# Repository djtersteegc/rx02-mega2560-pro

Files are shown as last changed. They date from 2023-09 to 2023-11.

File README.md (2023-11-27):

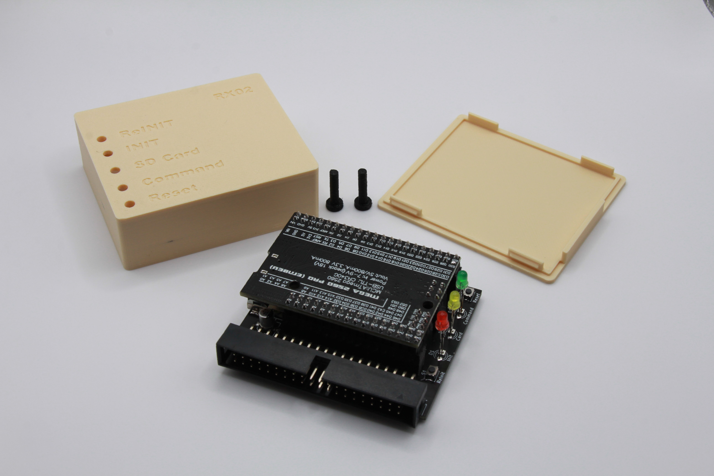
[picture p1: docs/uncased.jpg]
uncased


Mega 2560 Pro Embed version on [AK6DN's DEC RX02 emulator](https://github.com/AK6DN/rx02_emulator) board design and code.  There is a fork of his project at  https://github.com/djtersteegc/rx02_emulator that adds software support for this new board design. This was an exercise in how small I could make it while still using a Mega2560 shield and large'ish 0805 SMD parts for an easy DIY build.  If you are interested in a larger version built on a standard Arduino Mega 2560  with an LCD and buttons so you don't need to pick images via a serial/terminal connection, see my other project at https://github.com/djtersteegc/rx02-emulator-mega-shield.

Here's the two of them side by side on a Heathkit H11 for a size comparison.

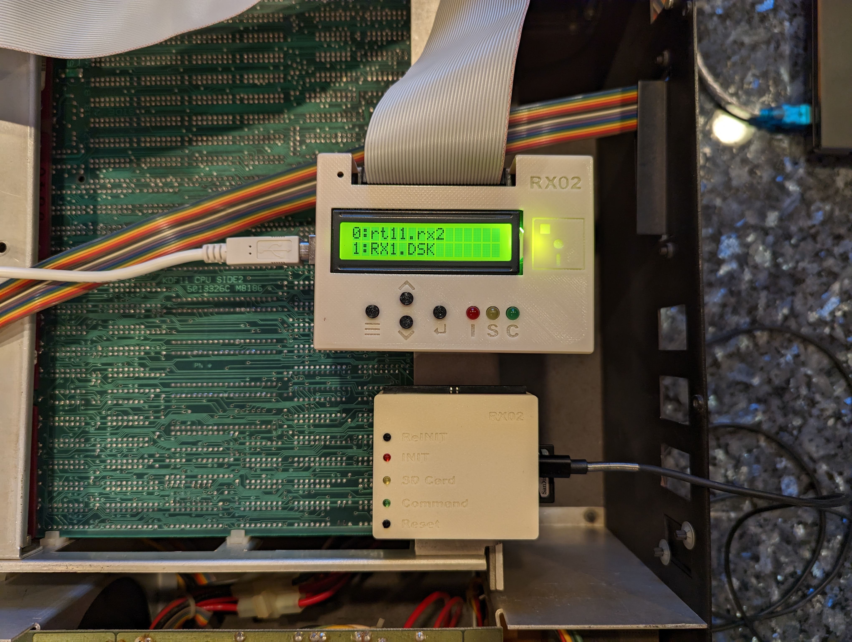
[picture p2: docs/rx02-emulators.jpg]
rx02-emulators


See the VCFed thread at https://forum.vcfed.org/index.php?threads/building-the-worlds-currently-smallest-rx02-emulator.1240496/ for discussion or help with this project

# BOM

There is an interactive BOM at https://djtersteegc.github.io/rx02-mega2560-pro/ibom-v1.2.html  It's for a version 1.2 board which is hasn't been produced yet so ignore R32 and D4 which are for a power indicator LED if you are building a version 1.1 board.

C1 and C2 are bulk storage caps for the 5V rail, any value over 33uF should do.  C7 is a 47uF tantalum to prevent sag on the 3.3V rail when hot swapping the SD card since there is usually quite a bit of in rush current.  You can probably do without, especially if you never intend to hot swap since it's not really supported by the firmware.

The SD card connector is commonly available from several different Chinese suppliers and often called "long body", "non popping", or"push pull".  Here's some links on LCSC.

https://www.lcsc.com/product-detail/SD-Card-Connectors_Hanbo-Electronic-SD-112_C961673.html

https://www.lcsc.com/product-detail/SD-Card-Connectors_XUNPU-SD-102_C266602.html

https://www.lcsc.com/product-detail/SD-Card-Connectors_Megastar-ZX-SD-282-8Y_C7419835.html

It should also cross with a Wurth 693063010911 or AMP GSD090012SEU if you want something domestically.

You can also use BSS138 FET's in place of the 2N7002's.

# Assembly

This time around I used the same resistor references as AK6DN's original version so his resistor stuffing table is the same. Most of the resistor footprints should NOT be populated.

| Signal | Resistor | Value | Resistor | Value |
| --- | --- | --- | --- | --- |
| RX_DMA_MODE_H  | R2 | - | R3 | **390** |
| RX_AC_L | R4 | **120** | R5 | - |
| RX_OUT_L | R6 | - | R7 | - |
| RX_SHIFT_L | R8 | - | R9 | - |
| RX_12BIT_L | R10 | **180** | R23 | **390** |
| RX_DATA_L | R11 | **180** | R12 | **390** |
| RX_DONE_L | R13 | - | R14 | - |
| RX_XFER_RQST_L | R15 | - | R16 | - |
| RX_INIT_L | R17 | - | R18 | **390** |
| RX_ERROR_L | R19 | - | R20 | - |
| RX_RUN_L | R21 | **180** | R22 | **390** |

Assemble the top side first.

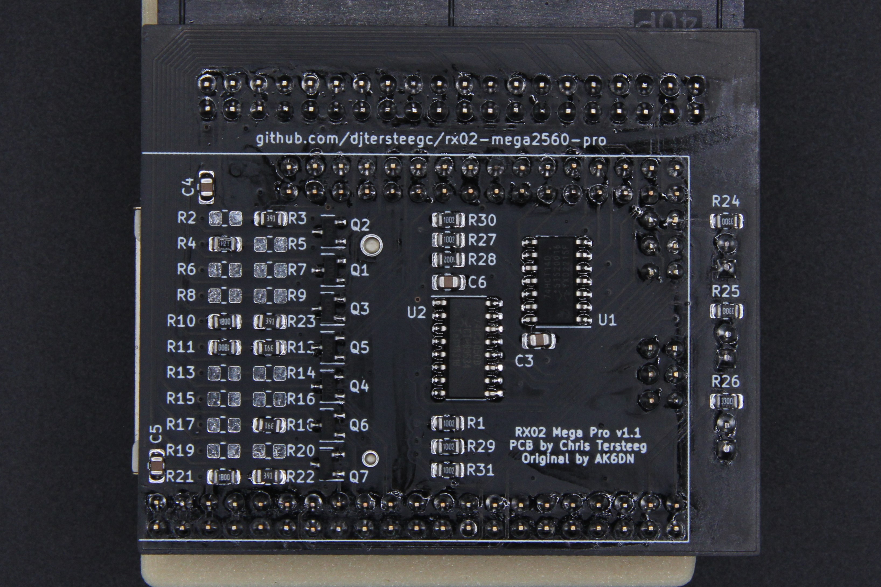
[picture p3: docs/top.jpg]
top


Then flip in over and do the bottom.  Followed by the headers and then the 40 pin connector. For the LED's, I first insert them in the PCB, then the PCB in the case, flip it over and support the case ~1mm off the work surface for the LED's to just poke through the top and get a nice reveal. Solder one leg on the LED's, flip it over to check your spacing again, and then solder the other leg.

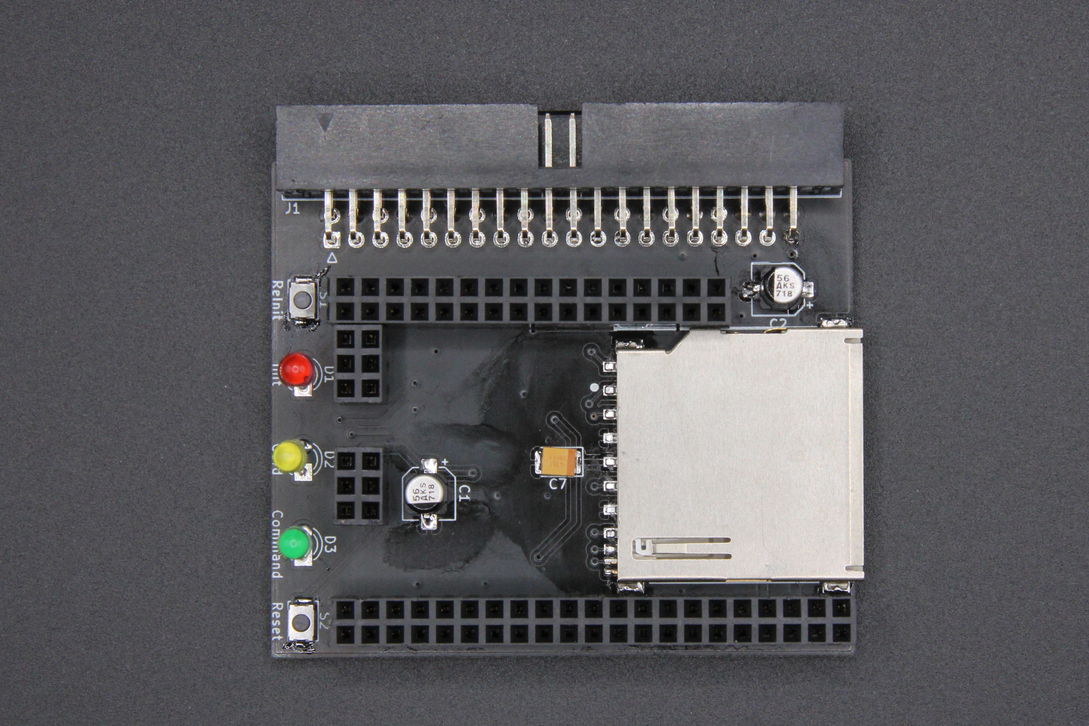
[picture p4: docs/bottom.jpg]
bottom


# Case

Make sure to print two copies of the buttons. Angle the board in connector side first and it should drop in.  It's a snap fit design, so no screws needed to assemble.

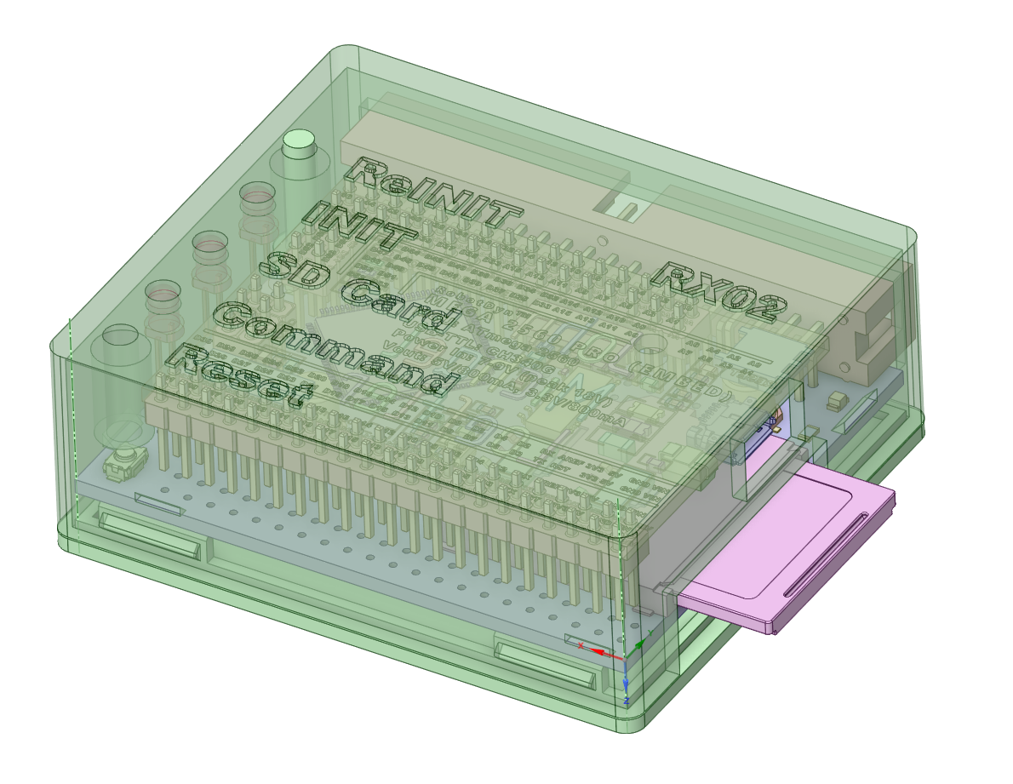
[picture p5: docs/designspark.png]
case


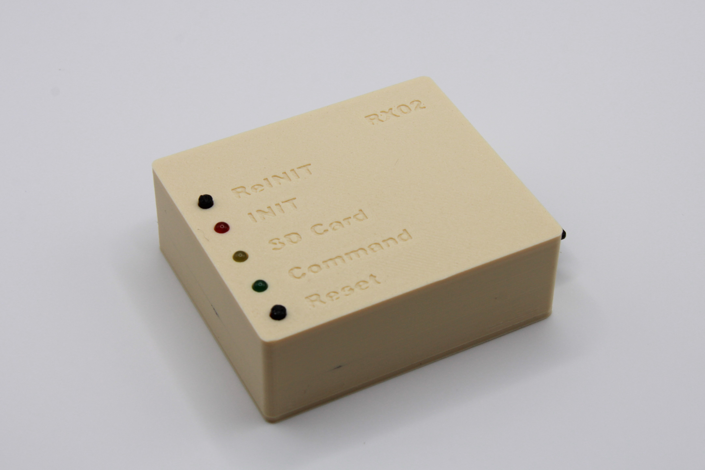
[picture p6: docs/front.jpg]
front


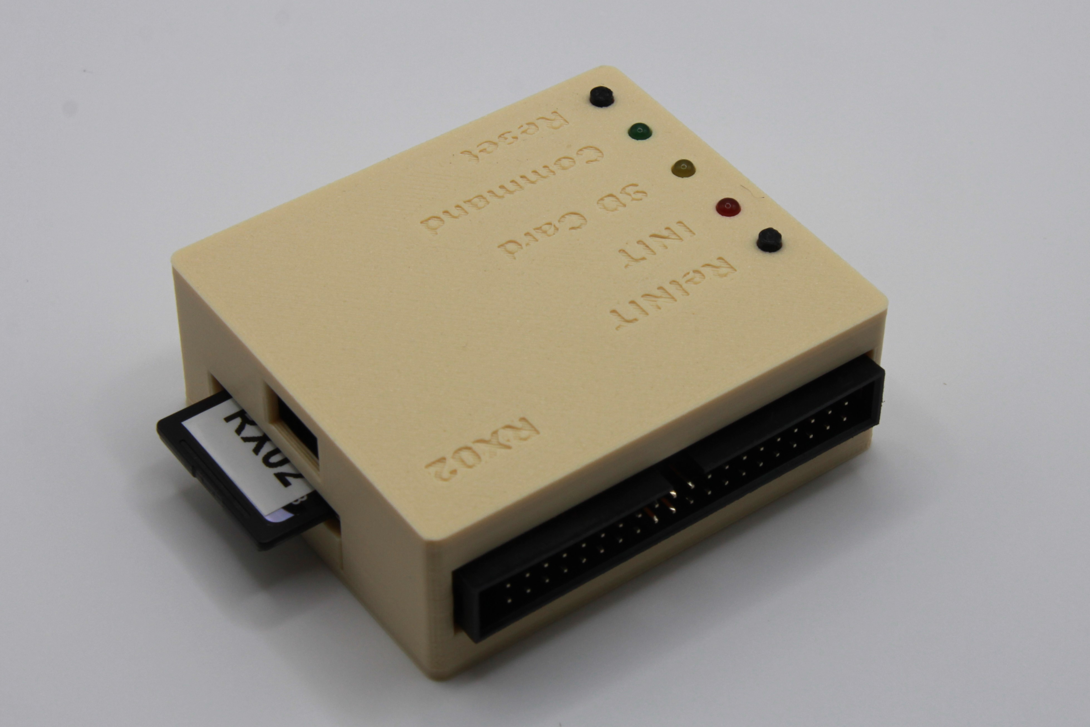
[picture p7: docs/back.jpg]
back


# Flashing and Usage

See instructions at https://github.com/djtersteegc/rx02_emulator

# Getting a Board

If you are in the US, hit me up on the [VCFed thread](https://forum.vcfed.org/index.php?threads/building-the-worlds-currently-smallest-rx02-emulator.1240496/) above and if I still have extras, I can drop one in the mail for a couple of bucks. Otherwise, grab the gerbers and fab your own.

# Hardware Revisions

### Version 1.0

Required bodge wires since I failed to pick interrupt enabled pins on the Mega2560 for the RX_INIT and RX_RUN lines when I reamapped the pins to better fit this layout.

### Versions 1.1 (Current)

Working

### Version 1.2 (Not Produced Yet)

Added a power LED

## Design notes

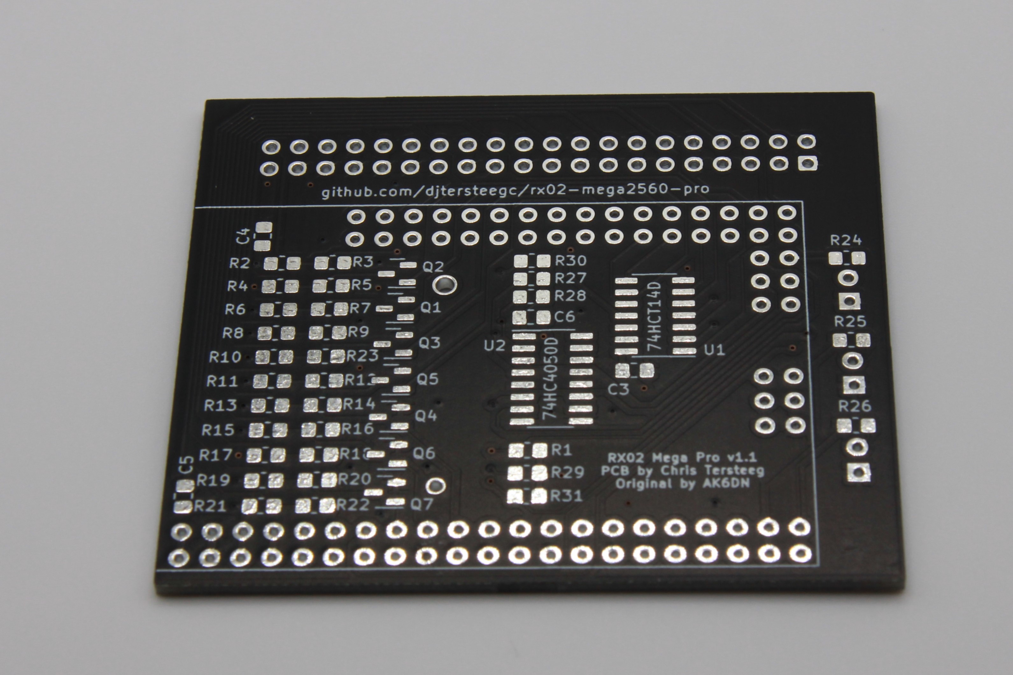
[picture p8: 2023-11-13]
docs/pcb-top.jpg

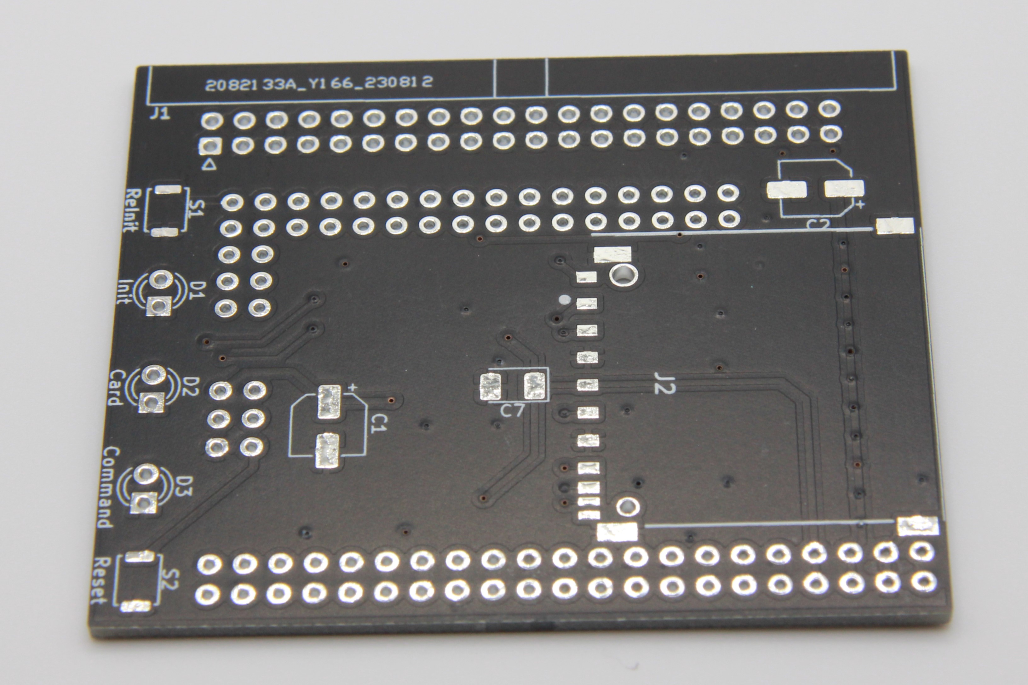
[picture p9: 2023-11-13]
docs/pcb-bottom.jpg

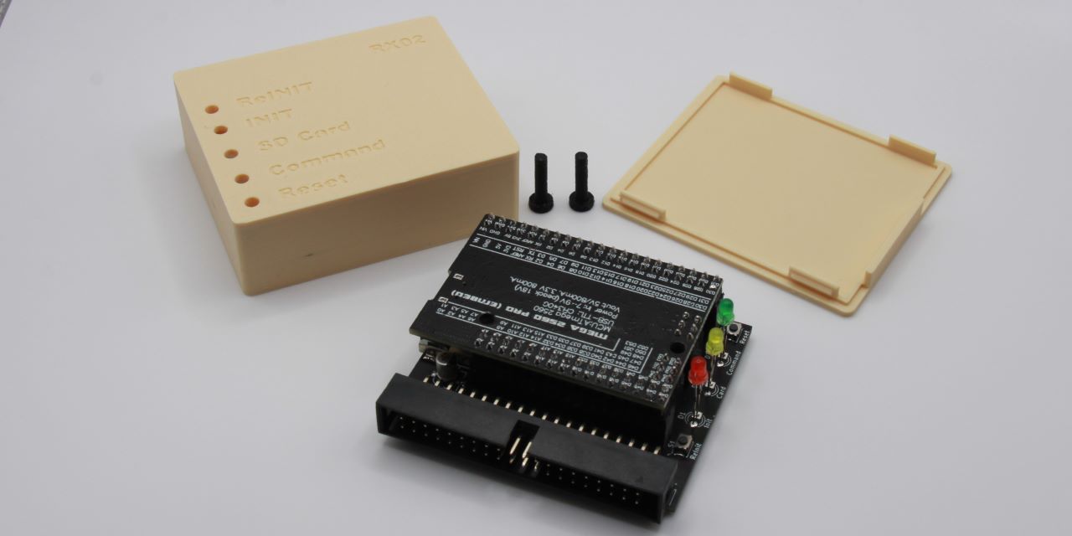
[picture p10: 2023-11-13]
docs/social.jpg

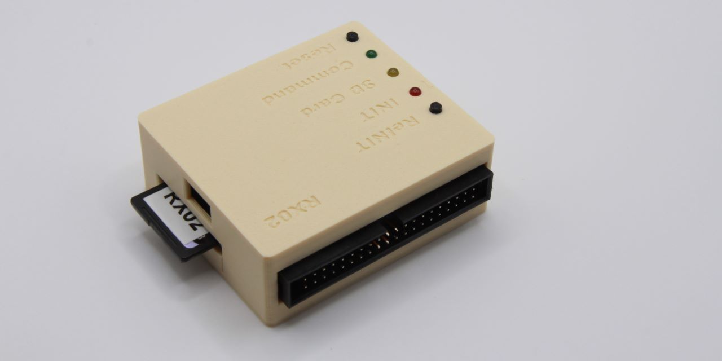
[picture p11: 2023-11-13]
docs/social2.jpg

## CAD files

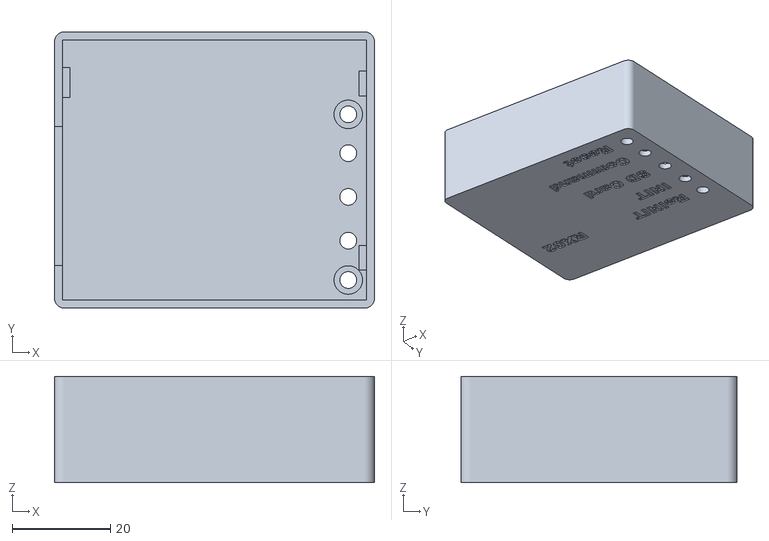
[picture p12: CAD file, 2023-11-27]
case/STL/rx02-mega2560-pro-body.stl
65.0 x 56.1 x 21.6

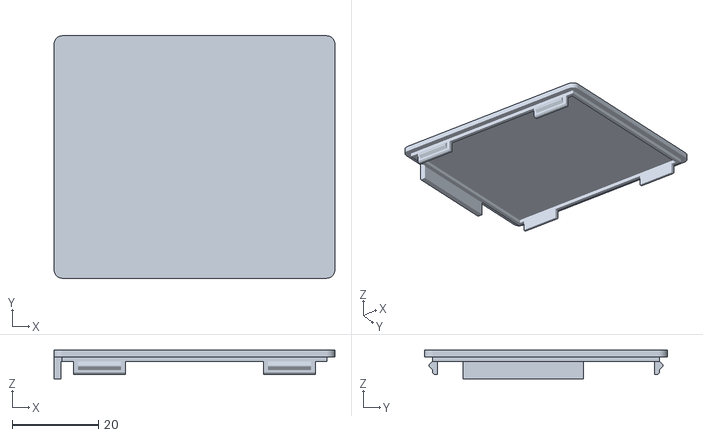
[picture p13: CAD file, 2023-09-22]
case/STL/rx02-mega2560-pro-lid.stl
65.0 x 56.1 x 6.68

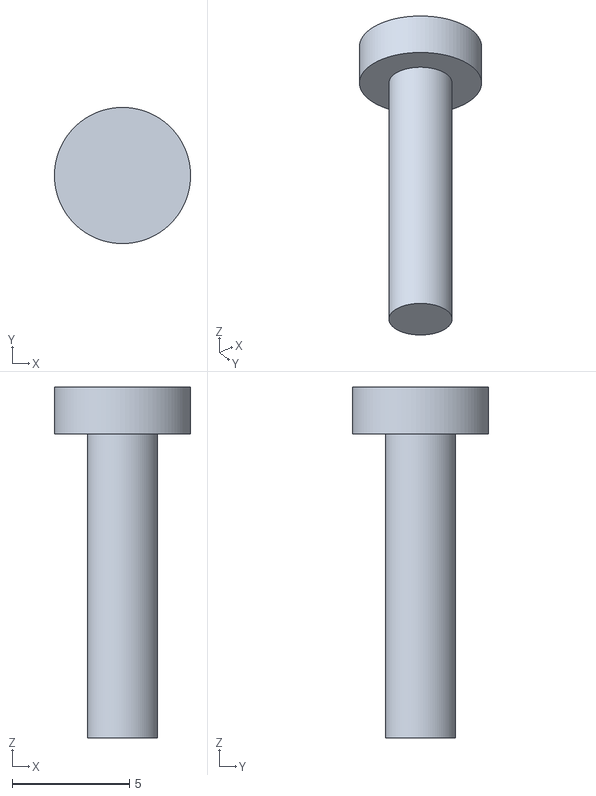
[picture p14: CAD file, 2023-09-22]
case/STL/rx02-mega2560-button.stl
5.80 x 5.80 x 15.0

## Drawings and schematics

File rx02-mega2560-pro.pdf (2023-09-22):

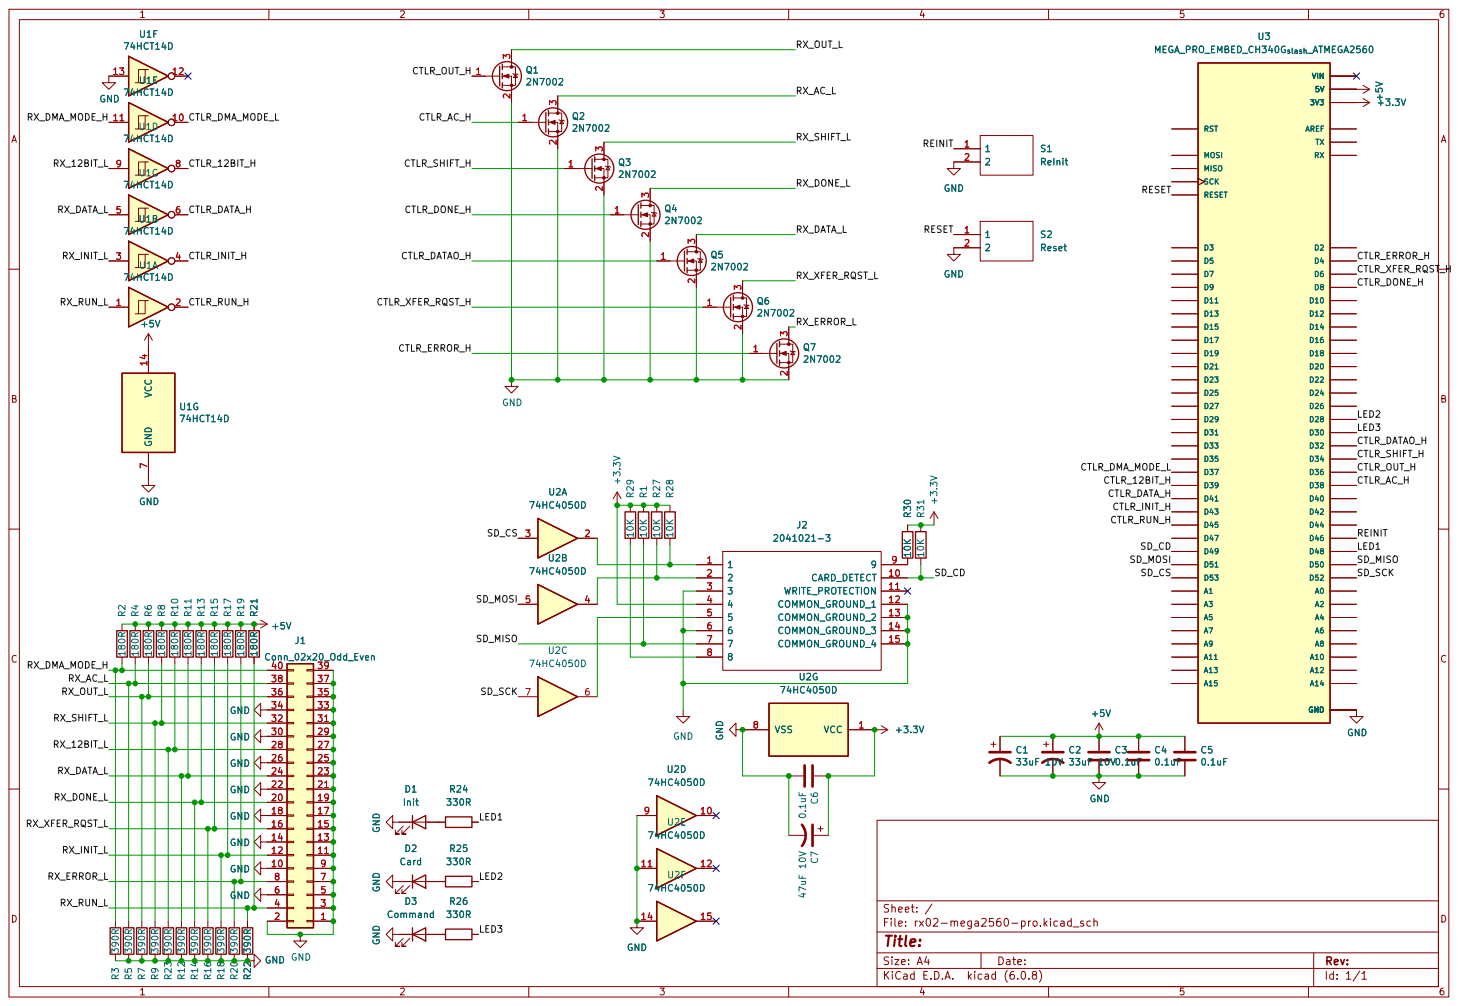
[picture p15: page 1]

2 2
3 3

5 5
6 6

Init GND GND GND

Init GND GND GND GND GND GND GND

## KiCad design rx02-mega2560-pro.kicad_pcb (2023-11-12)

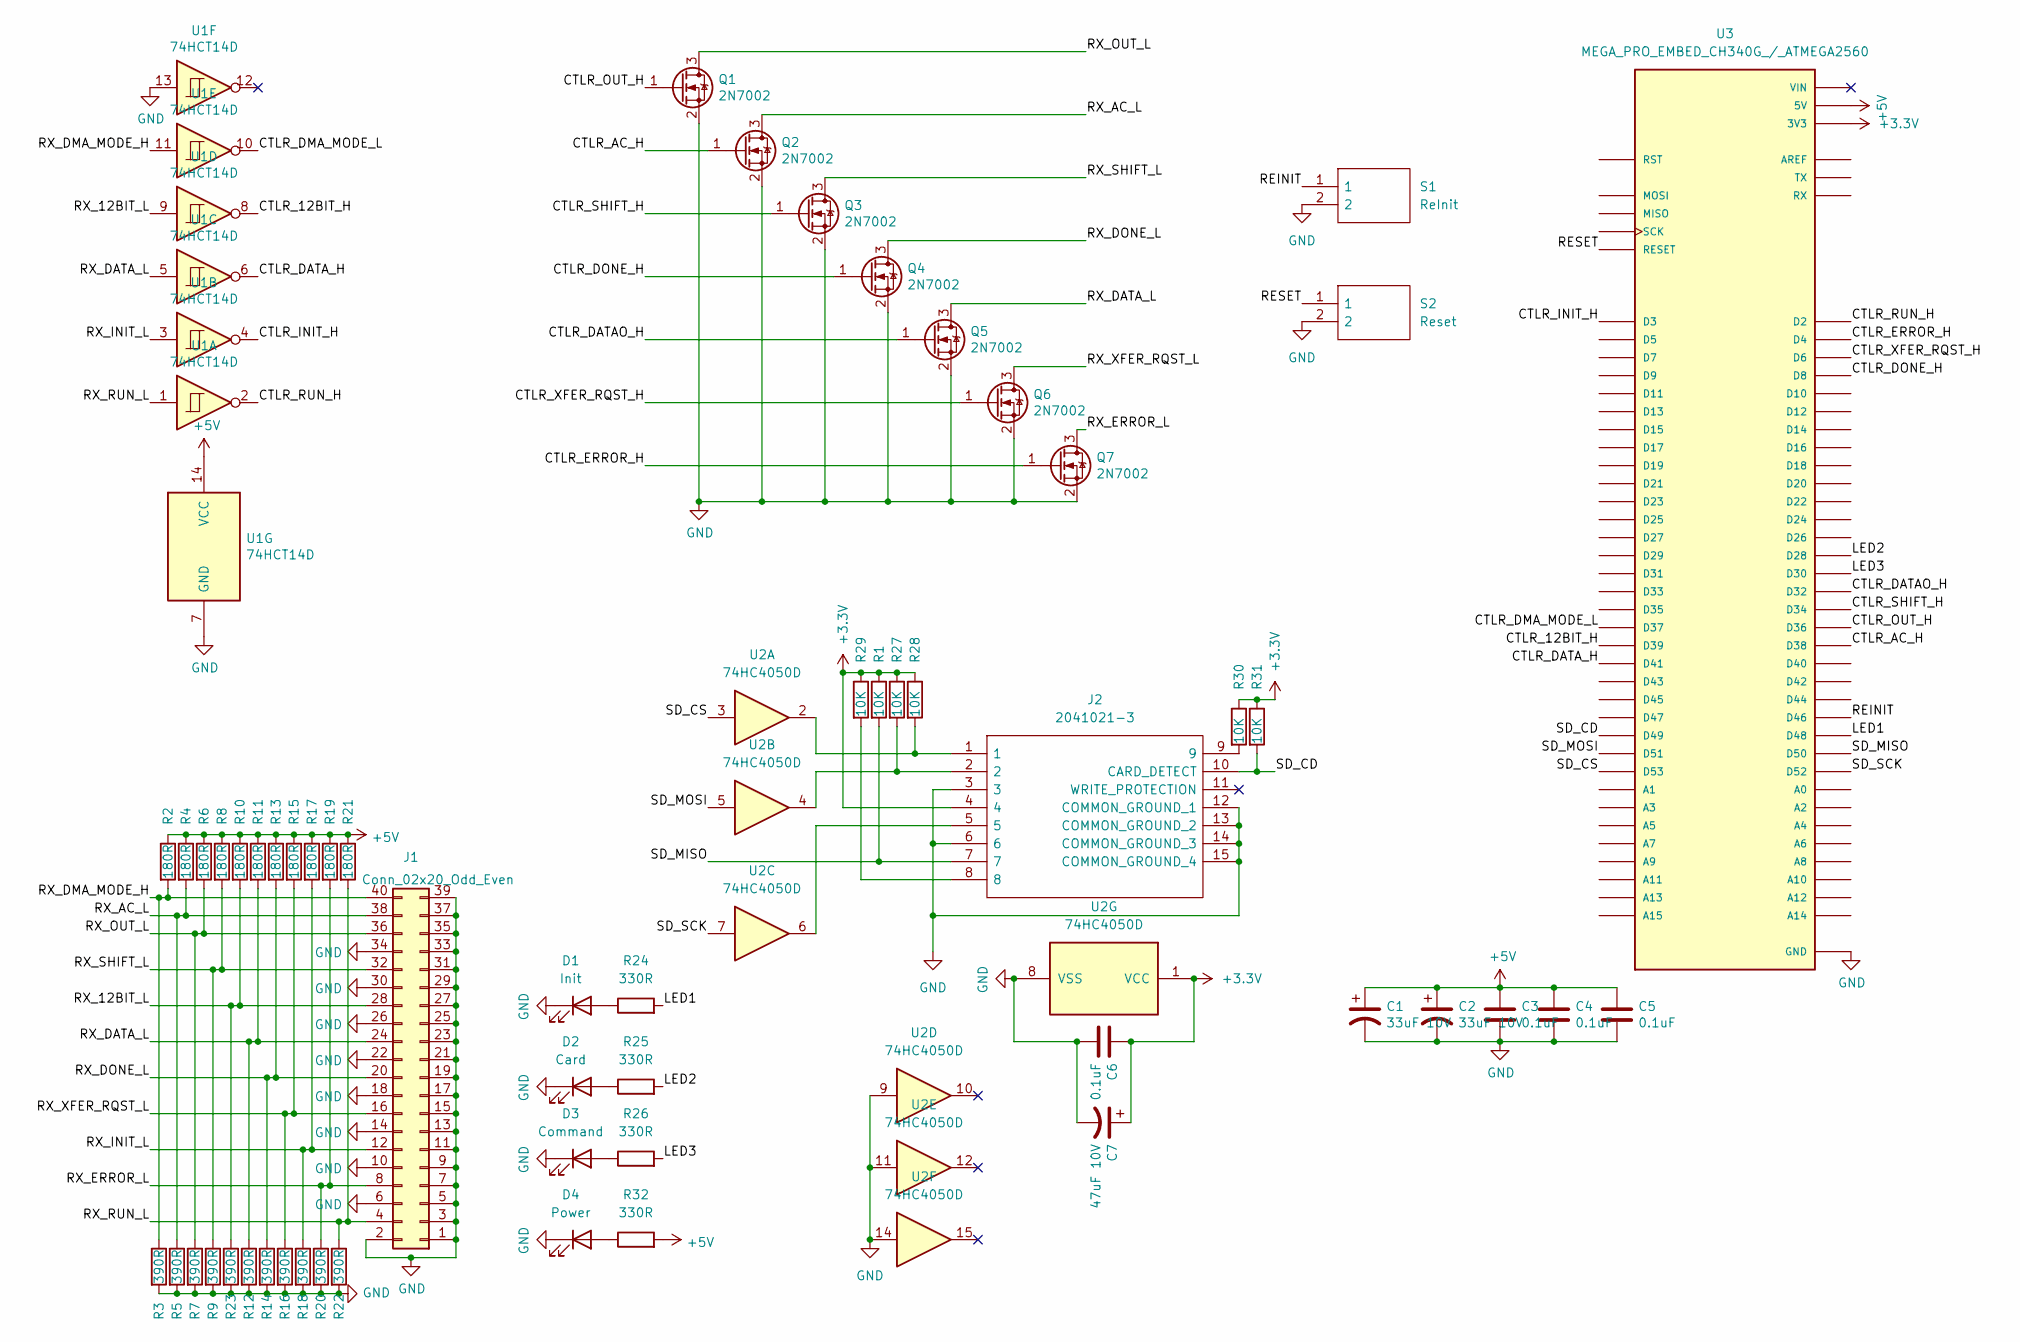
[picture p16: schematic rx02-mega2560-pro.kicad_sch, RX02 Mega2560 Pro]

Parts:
C1, C2: 33uF 10V; CP_Elec_5x5.8
C3, C4, C5, C6: 0.1uF; C_0805_2012Metric_Pad1.18x1.45mm_HandSolder
C7: 47uF 10V; CP_EIA-3528-12_Kemet-T_Pad1.50x2.35mm_HandSolder
D1: Init; LED_D3.0mm
D2: Card; LED_D3.0mm
D3: Command; LED_D3.0mm
D4: Power; LED_0805_2012Metric_Pad1.15x1.40mm_HandSolder
J1: Conn_02x20_Odd_Even; IDC-Header_2x20_P2.54mm_Horizontal
J2: 2041021-3; 2041021-3_2; Manufacturer_Part_Number 2041021-3; Mouser Part Number 571-2041021-3
Q1, Q2, Q3, Q4, Q5, Q6, Q7: 2N7002; SOT-23
R1, R27, R28, R29, R30, R31: 10K; R_0805_2012Metric_Pad1.20x1.40mm_HandSolder
R2, R4, R6, R8, R10, R11, R13, R15, R17, R19, R21: 180R; R_0805_2012Metric_Pad1.20x1.40mm_HandSolder
R3, R5, R7, R9, R12, R14, R16, R18, R20, R22, R23: 390R; R_0805_2012Metric_Pad1.20x1.40mm_HandSolder
R24, R25, R26, R32: 330R; R_0805_2012Metric_Pad1.20x1.40mm_HandSolder
S1: ReInit; SW_Push_SPST_NO_Alps_SKRK; Manufacturer_Part_Number SKRKAEE020; Mouser Part Number 688-SKRKAEE020
S2: Reset; SW_Push_SPST_NO_Alps_SKRK; Manufacturer_Part_Number SKRKAEE020; Mouser Part Number 688-SKRKAEE020
U1: 74HCT14D; SOIC-14_3.9x8.7mm_P1.27mm
U2: 74HC4050D; SOIC-16_3.9x9.9mm_P1.27mm
U3: MEGA_PRO_EMBED_CH340G_/_ATMEGA2560; MODULE_MEGA_PRO_EMBED_CH340G___ATMEGA2560; PARTREV 12/May/2017

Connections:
+3V3: C6.1, C7.1, J2.4, R1.1, R27.1, R28.1, R29.1, R30.1, R31.1, U2.1 (VCC), U3.3V3_1 (3V3), U3.3V3_2 (3V3)
+5V: C1.1, C2.1, C3.1, C4.1, C5.1, R2.1, R4.1, R6.1, R8.1, R10.1, R11.1, R13.1, R15.1, R17.1, R19.1, R21.1, R32.2, U1.14 (VCC), U3.5V_1 (5V), U3.5V_2 (5V), U3.5V_3 (5V)
/CTLR_12BIT_H: U1.8, U3.D39
/CTLR_AC_H: Q2.1 (G), U3.D38
/CTLR_DATAO_H: Q5.1 (G), U3.D32
/CTLR_DATA_H: U1.6, U3.D41
/CTLR_DMA_MODE_L: U1.10, U3.D37
/CTLR_DONE_H: Q4.1 (G), U3.D8
/CTLR_ERROR_H: Q7.1 (G), U3.D4
/CTLR_INIT_H: U1.4, U3.D3
/CTLR_OUT_H: Q1.1 (G), U3.D36
/CTLR_RUN_H: U1.2, U3.D2
/CTLR_SHIFT_H: Q3.1 (G), U3.D34
/CTLR_XFER_RQST_H: Q6.1 (G), U3.D6
/LED1: R24.2, U3.D48
/LED2: R25.2, U3.D28
/LED3: R26.2, U3.D30
/REINIT: S1.1, U3.D46
/RESET: S2.1, U3.RESET
/RX_12BIT_L: J1.28, R10.2, R23.1, U1.9
/RX_AC_L: J1.38, Q2.3 (D), R4.2, R5.1
/RX_DATA_L: J1.24, Q5.3 (D), R11.2, R12.1, U1.5
/RX_DMA_MODE_H: J1.40, R2.2, R3.1, U1.11
/RX_DONE_L: J1.20, Q4.3 (D), R13.2, R14.1
/RX_ERROR_L: J1.8, Q7.3 (D), R19.2, R20.1
/RX_INIT_L: J1.12, R17.2, R18.1, U1.3
/RX_OUT_L: J1.36, Q1.3 (D), R6.2, R7.1
/RX_RUN_L: J1.4, R21.2, R22.1, U1.1
/RX_SHIFT_L: J1.32, Q3.3 (D), R8.2, R9.1
/RX_XFER_RQST_L: J1.16, Q6.3 (D), R15.2, R16.1
/SD_CD: J2.10 (CARD_DETECT), R31.2, U3.D49
/SD_CS: U2.3, U3.D53
/SD_MISO: J2.7, R1.2, U3.D50
/SD_MOSI: U2.5, U3.D51
/SD_SCK: U2.7, U3.D52
GND: C1.2, C2.2, C3.2, C4.2, C5.2, C6.2, C7.2, D1.1 (K), D2.1 (K), D3.1 (K), D4.1 (K), J1.1, J1.2, J1.3, J1.5, J1.6, J1.7, J1.9, J1.10, J1.11, J1.13, J1.14, J1.15, J1.17, J1.18, J1.19, J1.21, J1.22, J1.23, J1.25, J1.26, J1.27, J1.29, J1.30, J1.31, J1.33, J1.34, J1.35, J1.37, J1.39, J2.3, J2.6, J2.12 (COMMON_GROUND_1), J2.13 (COMMON_GROUND_2), J2.14 (COMMON_GROUND_3), J2.15 (COMMON_GROUND_4), Q1.2 (S), Q2.2 (S), Q3.2 (S), Q4.2 (S), Q5.2 (S), Q6.2 (S), Q7.2 (S), R3.2, R5.2, R7.2, R9.2, R12.2, R14.2, R16.2, R18.2, R20.2, R22.2, R23.2, S1.2, S2.2, U1.7 (GND), U1.13, U2.8 (VSS), U2.9, U2.11, U2.14, U3.GND_1 (GND), U3.GND_2 (GND), U3.GND_3 (GND)
unnamed: D1.2 (A), R24.1
unnamed: D2.2 (A), R25.1
unnamed: D3.2 (A), R26.1
unnamed: D4.2 (A), R32.1
unnamed: J2.1, R28.2, U2.2
unnamed: J2.2, R27.2, U2.4
unnamed: J2.5, U2.6
unnamed: J2.8, R29.2
unnamed: J2.9, R30.2

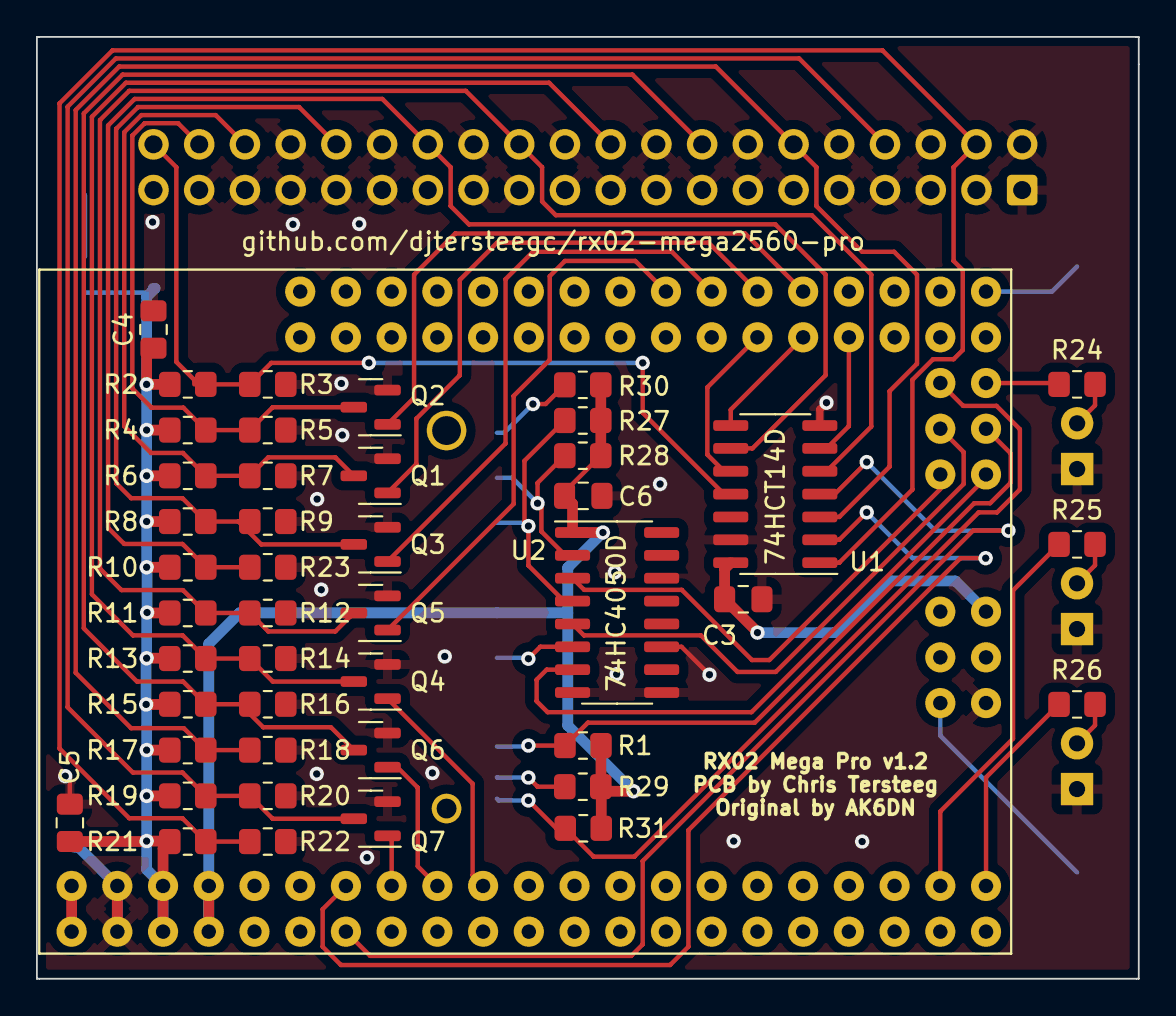
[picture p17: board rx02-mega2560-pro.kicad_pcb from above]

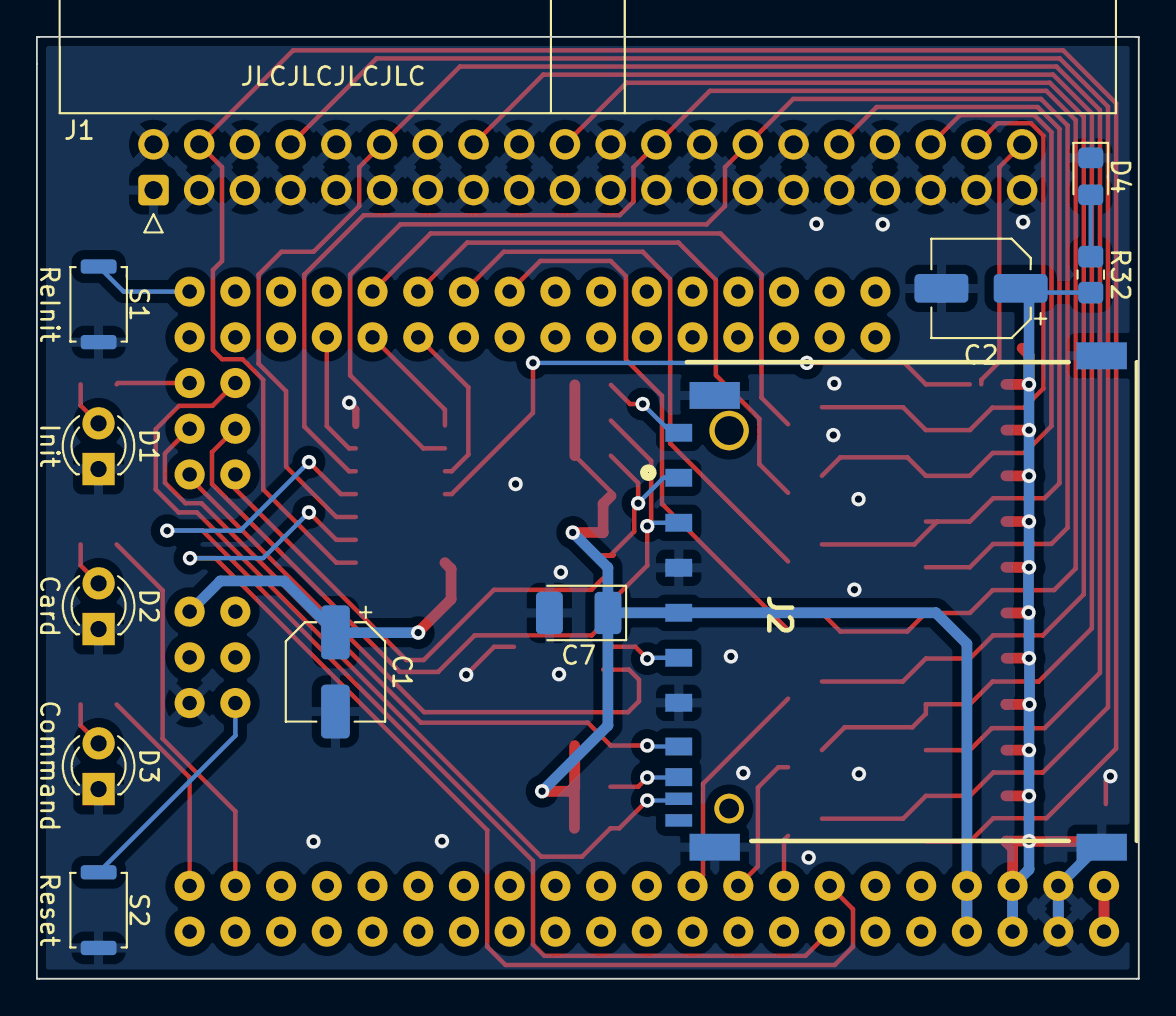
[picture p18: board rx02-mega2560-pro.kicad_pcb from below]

Board: 2 copper layers, 61.2 x 52.3 mm, 57 parts (12 on the bottom side), 45 nets.

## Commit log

2023-09-22 Update PCB to v1.1
    [rx02-mega2560-button.stl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]
2023-09-22 Add pin mapping file
    [PIN Mappings.csv]
2023-11-12 Update to v1.2, add some more docs
    [rx02-mega2560-pro-B_Cu.gbr, rx02-mega2560-pro-B_Mask.gbr, rx02-mega2560-pro-B_Paste.gbr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]
2023-11-13 Add termination resistor table
2023-11-27 Remove extra PCB stops in body that prevented the insertion of board at an angle
    [rx02-mega2560-pro-body.stl]
2023-11-27 Update PIN Mappings for boards types
    [PIN Mappings.csv, PIN Mappings.xlsx]
2025-02-28 Reorganize case files and add STEP exports
    [rx02-mega2560-button.stl, rx02-mega2560-pro-body.stl, rx02-mega2560-pro-lid.stl]
